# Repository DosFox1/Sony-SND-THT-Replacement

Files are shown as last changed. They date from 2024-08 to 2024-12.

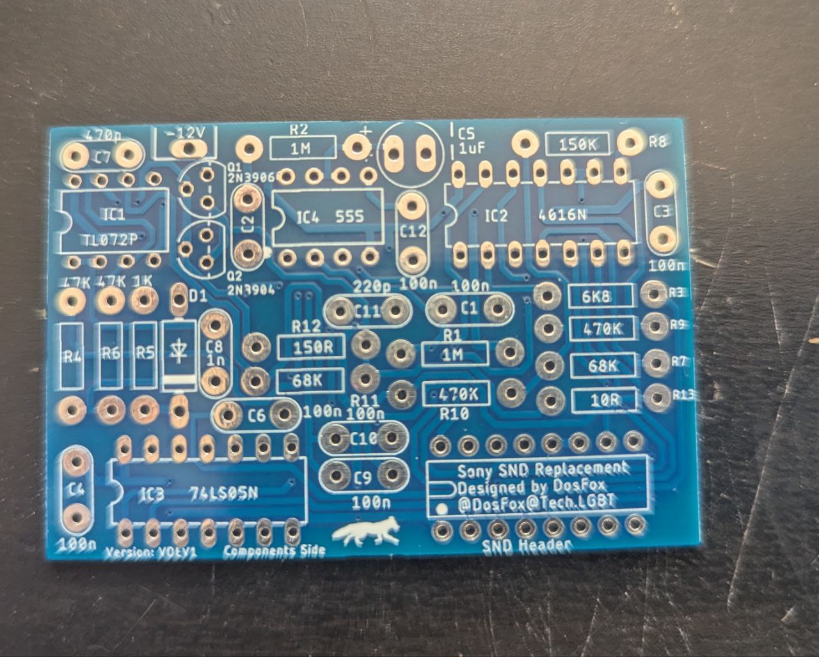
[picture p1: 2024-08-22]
Images/Sony SND Replacement Bare PCB.png

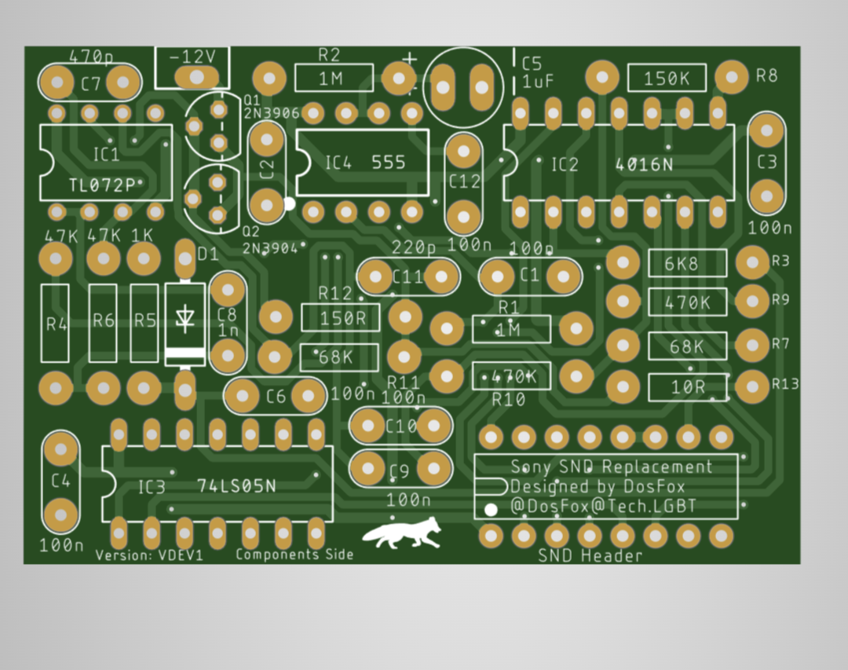
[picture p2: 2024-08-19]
Images/Sony SND Replacement Front.png

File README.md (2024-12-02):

# Sony SND THT Replacement 
A replacement for the Sony SND IC (part number 343-0045-A) as used on the Macintosh Plus, SE and others.
This was designed for the Macintosh Plus Clone project, but should be able to be used in other Macintoshes.

Screenshot_20240816-162321~2

**So, What Is It?**

The Sony SND is a custom IC, developed by Sony for the Macintosh Plus. 
It has three main functions - volume control, audio amplification, as well as providing the POR (Power On Reset) signal for the system. 
The original IC represents one of three custom pieces of silicon found with the Macintosh Plus. 

This board replaces the original Sony SND with equivalent circuitry. 
The Power On Reset deisgn is taken from the book _The 68000 microprocessor : hardware and software principles and applications_
This is currently available on the internet archive: https://archive.org/details/68000microproces00jame

Whereas the design for the audio amplification and volume control was taken from the original Macintosh 128/512 schematics:
https://forums.macrumors.com/threads/macintosh-512k-schematic.2291827/

**Parts List**

The SND is comprised of relatively easy to find, off the shelf parts:
```blocks
C1       100n 50V       100N_TH_CAP            CAP_5.08MM_PITCH 1
C2       100n 50V       100N_TH_CAP            CAP_5.08MM_PITCH 1
C3       100n 50V       100N_TH_CAP            CAP_5.08MM_PITCH 1
C4       100n 50V       100N_TH_CAP            CAP_5.08MM_PITCH 1
C5       1u 50V         1U_TH_ELEC_CAPVERTICAL CAP_ELECTROLYTIC 1
C6       100n 50V       100N_TH_CAP            CAP_5.08MM_PITCH 1
C7       470p 50V       470P_TH_CAP            CAP_5.08MM_PITCH 1
C8       1n 50V         1N_TH_CAP              CAP_5.08MM_PITCH 1
C9       100n 50V       100N_TH_CAP            CAP_5.08MM_PITCH 1
C10      100n 50V       100N_TH_CAP            CAP_5.08MM_PITCH 1
C11      220p 50V       220P_TH_CAP            CAP_5.08MM_PITCH 1
D1       5.1V Zener     ZENER-DIODEF126-10     F126Z10          1
IC1      TL072P         TL072P                 DIL08            1
IC2      4016N          4016N                  DIL14            1
IC3      74LS05N        74LS05N                DIL14            1
IC4      555            555P                   DIP08            1
CN1      Header         Turned Pin Header      DIP16 Header     16
Q1       2N3906         2N3906                 TO92             1
Q2       2N3904         2N3904                 TO92D            1
R1       1M             1M_TH_RESISTOR         RESISTORTHRUHOLE 1
R2       1M             1M_TH_RESISTOR         RESISTORTHRUHOLE 1
R3       6k8            6K8_TH_RESISTOR        RESISTORTHRUHOLE 1
R4       47k            47K_TH_RESISTOR        RESISTORTHRUHOLE 1
R5       1k             1K_TH_RESISTOR         RESISTORTHRUHOLE 1
R6       47k            47K_TH_RESISTOR        RESISTORTHRUHOLE 1
R7       68k            68K_TH_RESISTOR        RESISTORTHRUHOLE 1
R8       150k           150K_TH_RESISTOR       RESISTORTHRUHOLE 1
R9       470k           470K_TH_RESISTOR       RESISTORTHRUHOLE 1
R10      470k           470K_TH_RESISTOR       RESISTORTHRUHOLE 1
R11      200k           200K_TH_RESISTOR       RESISTORTHRUHOLE 1
R12      150R           150R_TH_RESISTOR       RESISTORTHRUHOLE 1
R13      10R            10R_TH_RESISTOR        RESISTORTHRUHOLE 1
```

All components are through hole, and are designed to be easily soldered. 
The PCB can be sourced from your favoured fab house, I prefer JLCPCB (sorry PCBWay) - and only cost $4 for five boards. 

**Assembly Notes and Errata**

This design is the initial VDEV1 version of the SND replacement, and has been tested with the Macintosh Plus Clone project.



The design (being through hole) is unlikely to fit into an existing Macintosh chassis, and was designed as a
"first stab" attempt at making a replacement SND. It is anticipated that a secondary improved SMD design will be more suited to this application.

The zener diode at D1 theoretically should be a 1N5231, but any similar 5.1v zener will suffice. 

Assembly should be fairly straight forward for those with some experience with electronic assembly.

Additionally, as the audio section is based off the original Macintosh 128K, -12V is required, which is not provided by the SND header. 
-12V can be tapped directly from the logic board - either from pin 2 (central pin) of the 7905 -5v regulator, pin 8 of the audio/power header
or from pin 5 of the MC3488 line driver. 
I heavily suggest checking with a multimeter before installation - this may damage the SND adapter, the Macintosh board, or both.

The board should be fitted so that the majority of the boards cover the 6522 and Z8530. It may be necessary to add a standard IC socket to raise the board.

Note - VDEV1 boards were assembled and worked first time. Also note that a TL082 can be subsistuted instead of the TL072 if needed.

# Important Assembly Note!
R11 should be a 200K resistor. It is erroneously marked as a 68K on VDEV1 boards. 
This has been fixed in V1.0

# Very Important Note:
Additionally - resistor R21 on the Macintosh Board itself needs to be snipped off, as this is a 47 ohm pull up to 5V on the POR circuit. 
No clue why Sony designed it this way, but it needs to be removed (or replaced with a 1M, and R1 on the Sony SND replacement DNF'd).

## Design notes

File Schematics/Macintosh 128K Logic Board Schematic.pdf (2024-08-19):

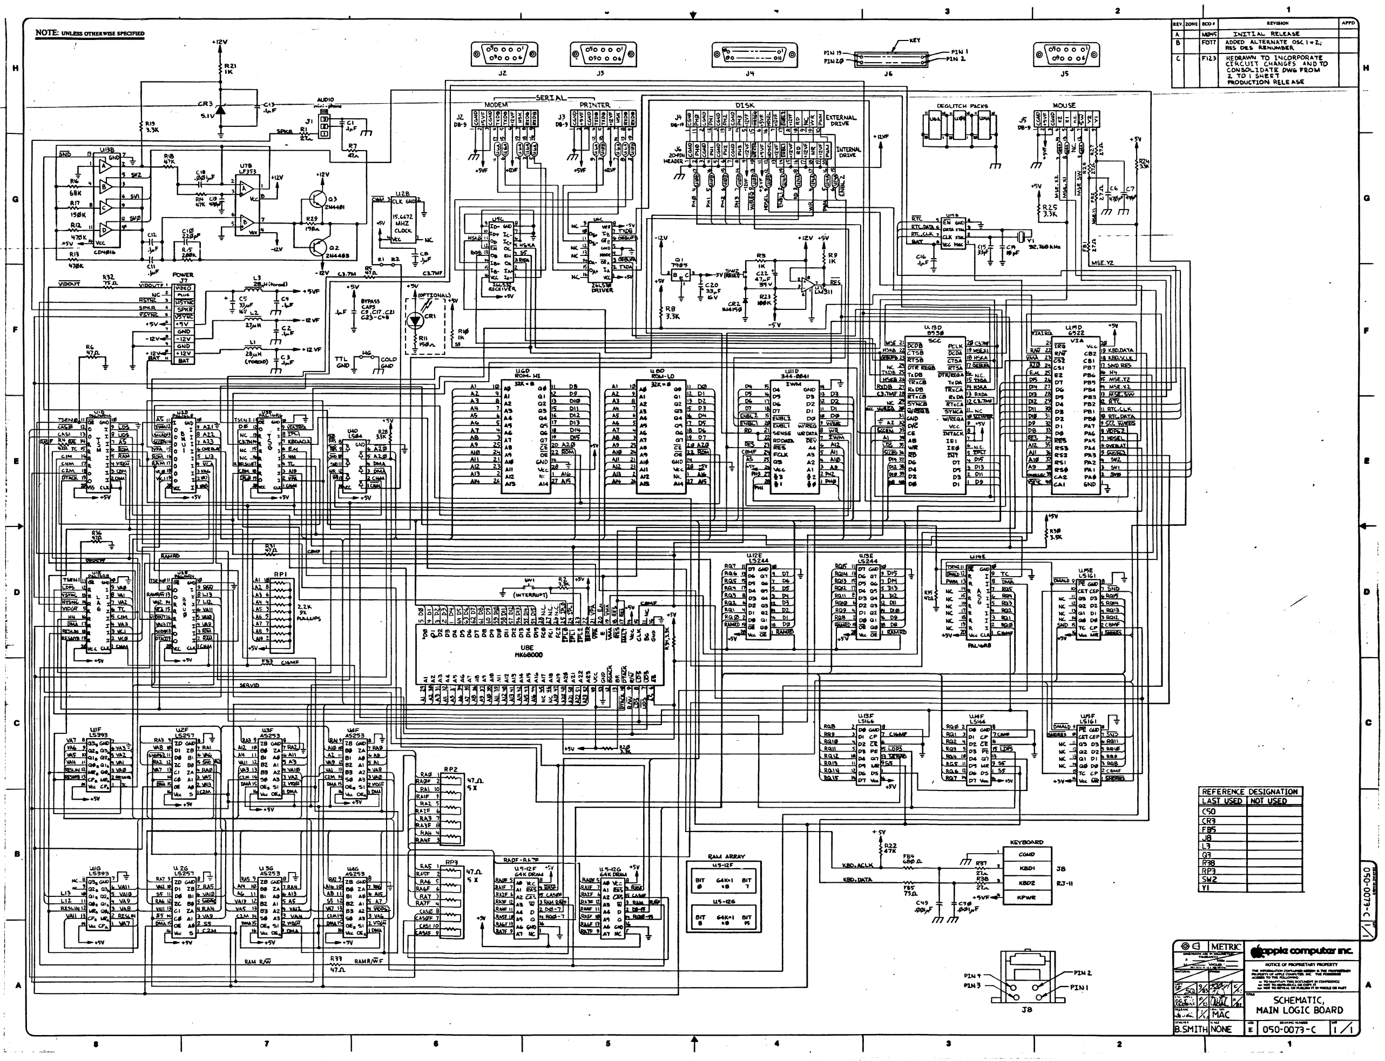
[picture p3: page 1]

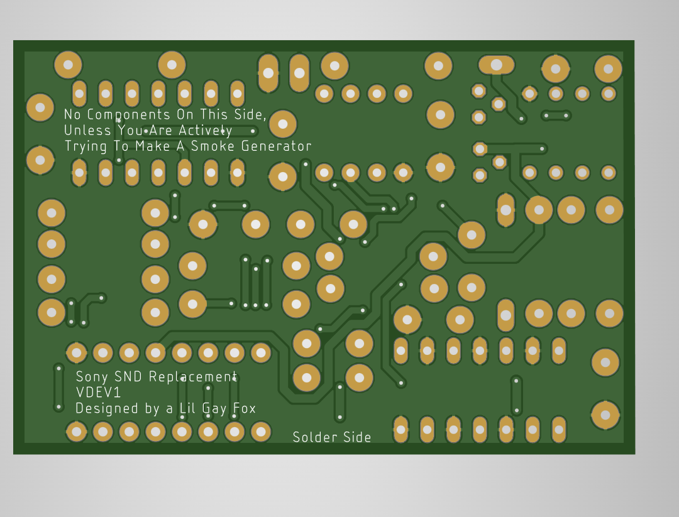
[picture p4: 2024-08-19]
Images/Sony SND Replacement Back.png

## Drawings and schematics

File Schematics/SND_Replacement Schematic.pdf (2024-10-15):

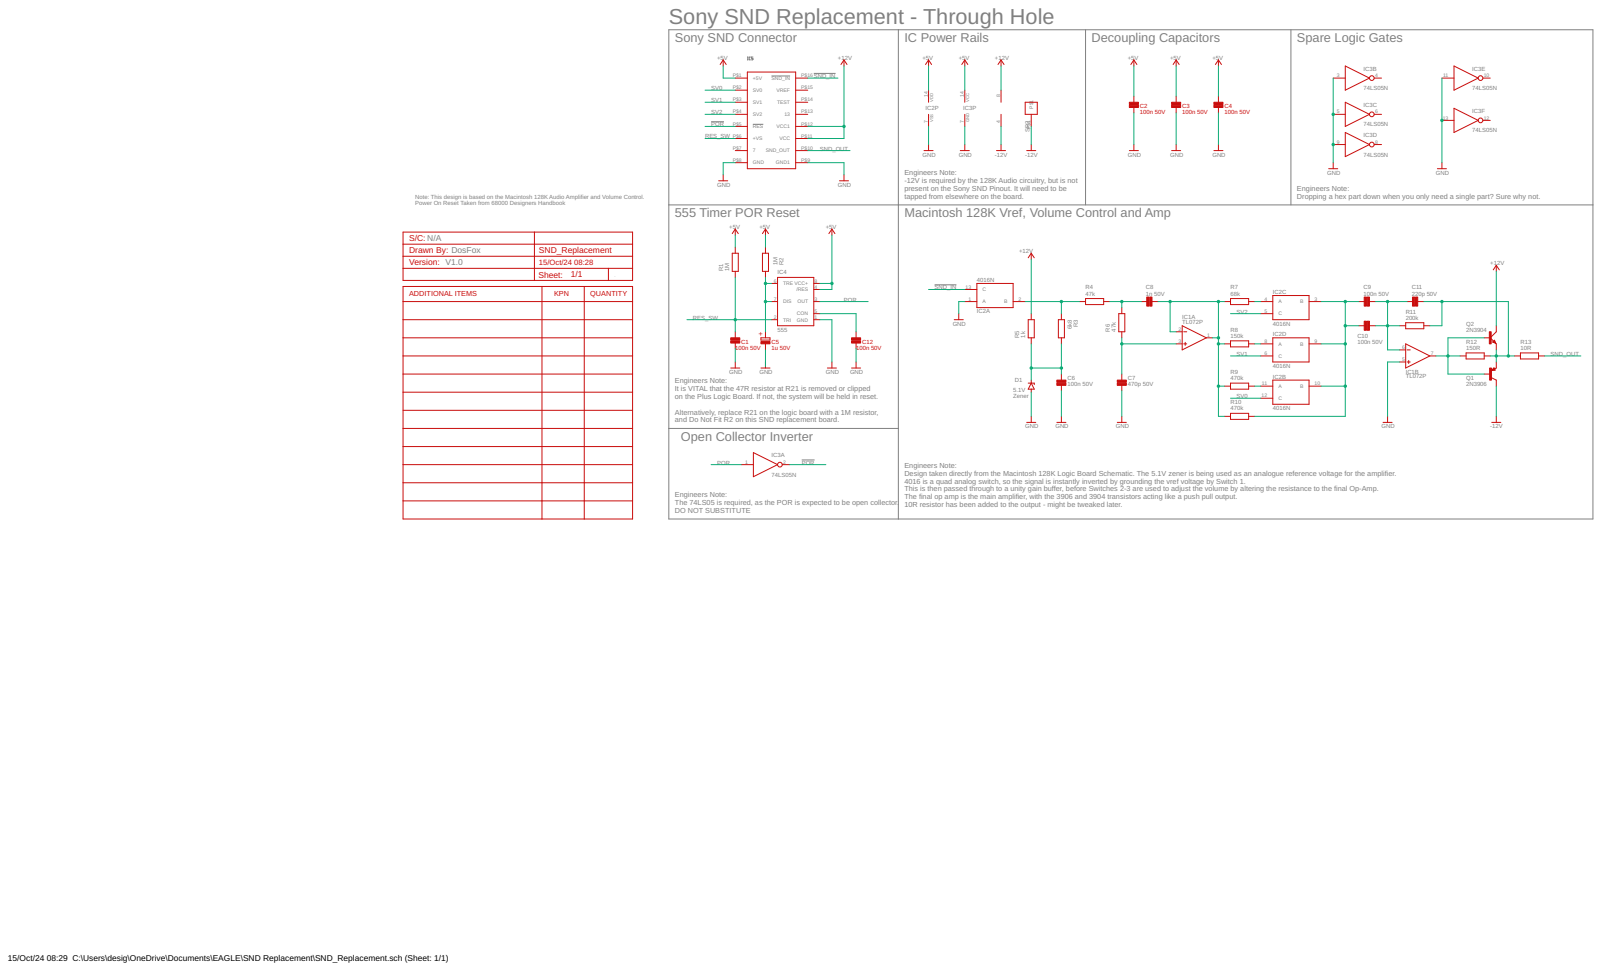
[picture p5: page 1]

Sony SND Replacement - Through Hole

Engineers Note: -12V is required by the 128K Audio circuitry, but is not

present on the Sony SND Pinout. It will need to be

Note: This design is based on the Macintosh 128K Audio Amplifier and Volume Control. Power On Reset Taken from 68000 Designers Handbook

Dropping a hex part down when you only need a single part? Sure why not. V1.0

Macintosh 128K Vref, Volume Control and Amp

S/C: N/A
Drawn By: DosFox | SND_Replacement
Version: | 15/Oct/24 08:28

Sheet: 1/1 | A1

Engineers Note:
It is VITAL that the 47R resistor at R21 is removed or clipped
on the Plus Logic Board. If not, the system will be held in reset. Alternatively, replace R21 on the logic board with a 1M resistor, and Do Not Fit R2 on this SND replacement board.

Design taken directly from the Macintosh 128K Logic Board Schematic. The 5.1V zener is being used as an analogue reference voltage for the amplifier. 4016 is a quad analog switch, so the signal is instantly inverted by grounding the vref voltage by Switch 1. This is then passed through to a unity gain buffer, before Switches 2-3 are used to adjust the volume by altering the resistance to the final Op-Amp. The final op amp is the main amplifier, with the 3906 and 3904 transistors acting like a push pull output. 10R resistor has been added to the output - might be tweaked later.

The 74LS05 is required, as the POR is expected to be open collector. DO NOT SUBSTITUTE

15/Oct/24 08:29 C:\Users\desig\OneDrive\Documents\EAGLE\SND Replacement\SND_Replacement.sch (Sheet: 1/1)

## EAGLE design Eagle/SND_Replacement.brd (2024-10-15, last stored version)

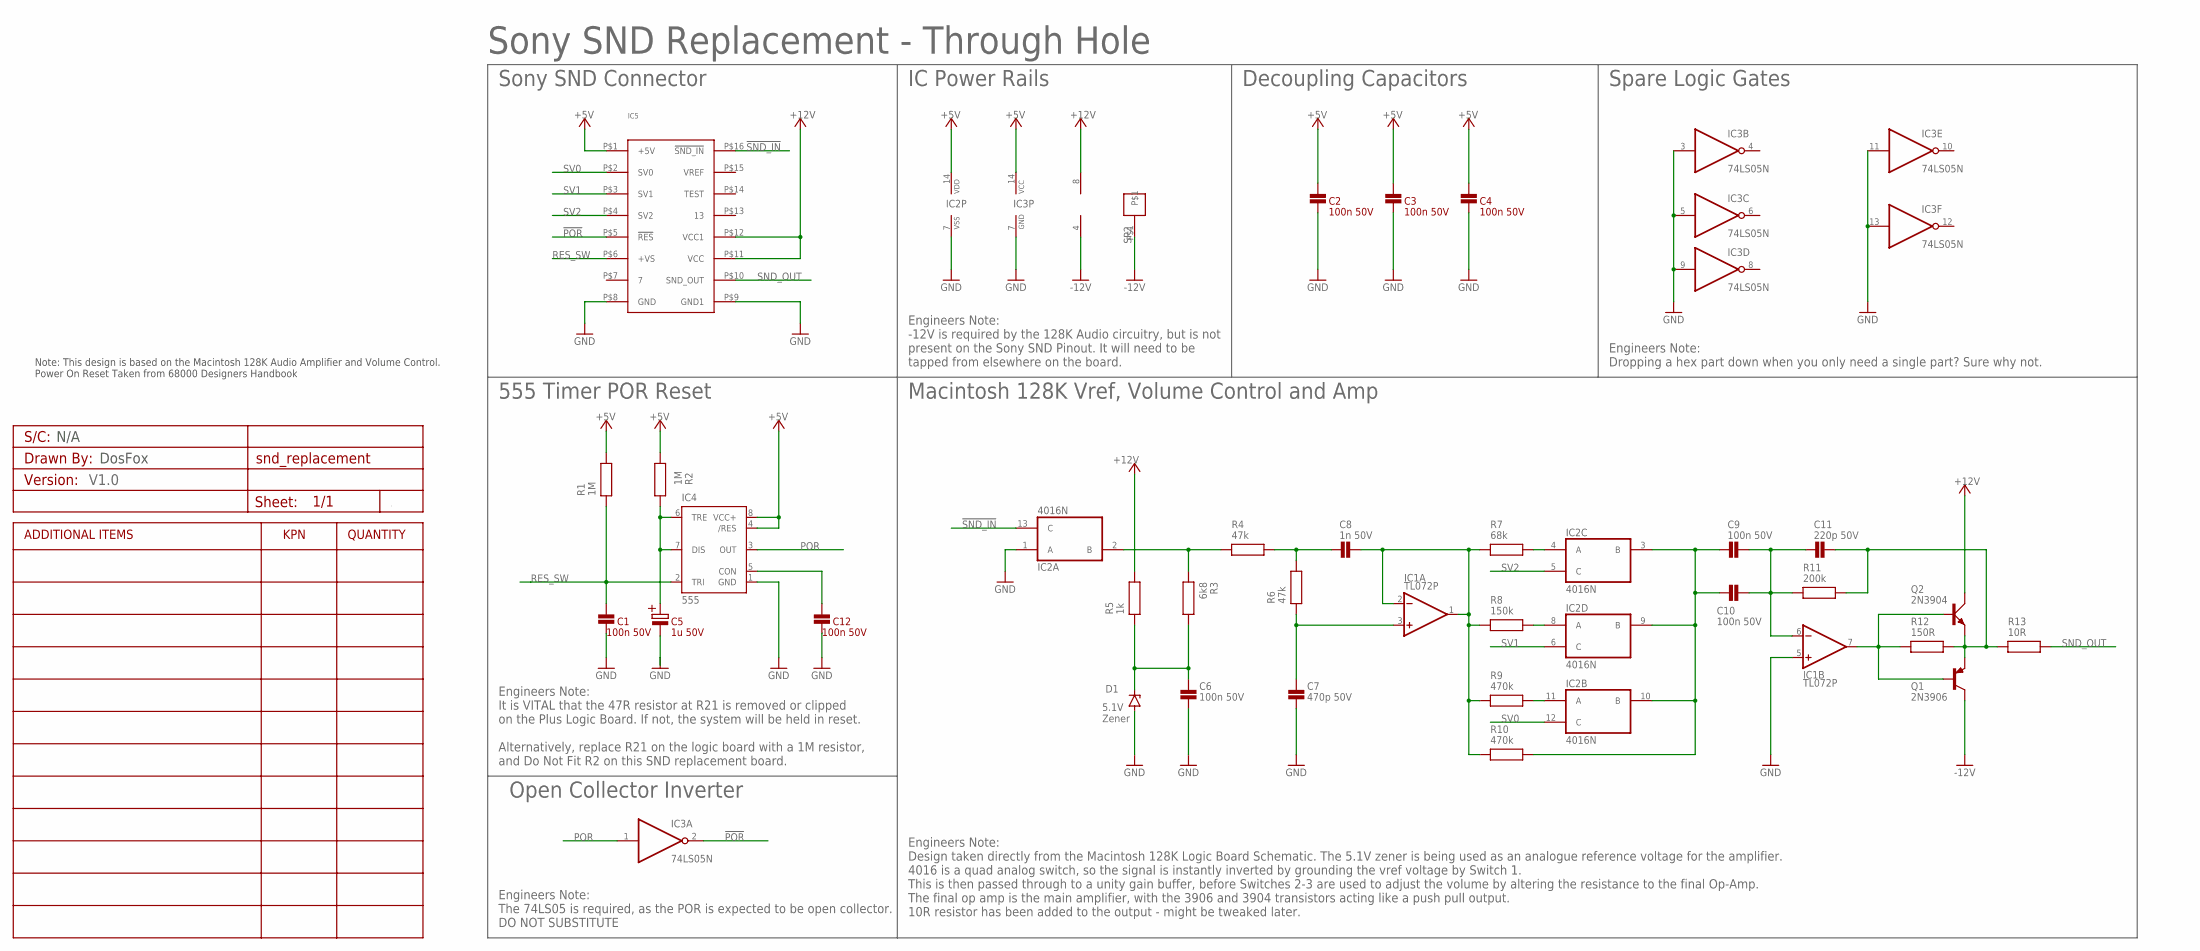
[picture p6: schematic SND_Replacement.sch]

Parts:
A1: V1.0; PCB_CUSTOM_DETAILS
C1, C2, C3, C4, C6, C9, C10, C12: 100n 50V; CAP_5.08MM_PITCH
C5: 1u 50V; CAP_ELECTROLYTIC
C7: 470p 50V; CAP_5.08MM_PITCH
C8: 1n 50V; CAP_5.08MM_PITCH
C11: 220p 50V; CAP_5.08MM_PITCH
D1: ZENER-DIODEF126-10; F126Z10
IC1: TL072P; DIL08
IC2: 4016N; DIL14
IC3: 74LS05N; DIL14
IC4: 555; DIP08
IC5: SND; DIP16
Q1: 2N3906; TO92
Q2: 2N3904; TO92D
R1, R2: 1M; RESISTORTHRUHOLE
R3: 6k8; RESISTORTHRUHOLE
R4, R6: 47k; RESISTORTHRUHOLE
R5: 1k; RESISTORTHRUHOLE
R7: 68k; RESISTORTHRUHOLE
R8: 150k; RESISTORTHRUHOLE
R9, R10: 470k; RESISTORTHRUHOLE
R11: 200k; RESISTORTHRUHOLE
R12: 150R; RESISTORTHRUHOLE
R13: 10R; RESISTORTHRUHOLE
SP2: 1PIN

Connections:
!POR: IC3.2 (O), IC5.P$5 (!RES)
!SND_IN: IC2.13 (C), IC5.P$16 (!SND_IN)
+5V: C2.P$2, C3.P$2, C4.P$2, IC2.14 (VDD), IC3.14 (VCC), IC4.4 (/RES), IC4.8 (VCC+), IC5.P$1 (+5V), R1.P$2, R2.P$2
+12V: IC1.8 (V+), IC5.P$11 (VCC), IC5.P$12 (VCC1), Q2.C, R5.P$2
-12V: IC1.4 (V-), Q1.1 (C), SP2.P$1
GND: C1.P$1, C2.P$1, C3.P$1, C4.P$1, C5.P$2, C6.P$1, C7.P$1, C12.P$1, D1.A, IC1.5 (+IN), IC2.1 (A), IC2.7 (VSS), IC3.3 (I), IC3.5 (I), IC3.7 (GND), IC3.9 (I), IC3.11 (I), IC3.13 (I), IC4.1 (GND), IC5.P$8 (GND), IC5.P$9 (GND1)
unnamed: IC2.2 (B), R3.P$1, R4.P$1
unnamed: C12.P$2, IC4.5 (CON)
unnamed: C9.P$1, C10.P$1, IC2.3 (B), IC2.9 (B), IC2.10 (B), R10.P$2
unnamed: C8.P$1, R4.P$2, R6.P$2
unnamed: C6.P$2, D1.C, R3.P$2, R5.P$1
unnamed: C7.P$2, IC1.3 (+IN), R6.P$1
unnamed: IC2.4 (A), R7.P$2
unnamed: IC2.8 (A), R8.P$2
unnamed: IC2.11 (A), R9.P$2
unnamed: C9.P$2, C10.P$2, C11.P$1, IC1.6 (-IN), R11.P$1
unnamed: C8.P$2, IC1.1 (OUT), IC1.2 (-IN), R7.P$1, R8.P$1, R9.P$1, R10.P$1
unnamed: C11.P$2, Q1.3 (E), Q2.E, R11.P$2, R12.P$2, R13.P$1
unnamed: IC1.7 (OUT), Q1.2 (B), Q2.B, R12.P$1
POR: IC3.1 (I), IC4.3 (OUT)
RES_SW: C1.P$2, IC4.2 (TRI), IC5.P$6 (+VS), R1.P$1
RES_SW1: C5.P$1, IC4.6 (TRE), IC4.7 (DIS), R2.P$1
SND_OUT: IC5.P$10 (SND_OUT), R13.P$2
SV0: IC2.12 (C), IC5.P$2 (SV0)
SV1: IC2.6 (C), IC5.P$3 (SV1)
SV2: IC2.5 (C), IC5.P$4 (SV2)

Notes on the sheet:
Note: This design is based on the Macintosh 128K Audio Amplifier and Volume Control. Power On Reset Taken from 68000 Designers Handbook
DosFox
N/A
5.1V Zener
Sony SND Replacement - Through Hole
Sony SND Connector
IC Power Rails
Decoupling Capacitors
Spare Logic Gates
555 Timer POR Reset
Open Collector Inverter
Macintosh 128K Vref, Volume Control and Amp
Engineers Note: Design taken directly from the Macintosh 128K Logic Board Schematic. The 5.1V zener is being used as an analogue reference voltage for the amplifier. 4016 is a quad analog switch, so the signal is instantly inverted by grounding the vref voltage by Switch 1. This is then passed thro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
Engineers Note: It is VITAL that the 47R resistor at R21 is removed or clipped on the Plus Logic Board. If not, the system will be held in reset. Alternatively, replace R21 on the logic board with a 1M resistor, and Do Not Fit R2 on this SND replacement board.
Engineers Note: The 74LS05 is required, as the POR is expected to be open collector. DO NOT SUBSTITUTE
Engineers Note: -12V is required by the 128K Audio circuitry, but is not present on the Sony SND Pinout. It will need to be tapped from elsewhere on the board.
Engineers Note: Dropping a hex part down when you only need a single part? Sure why not.

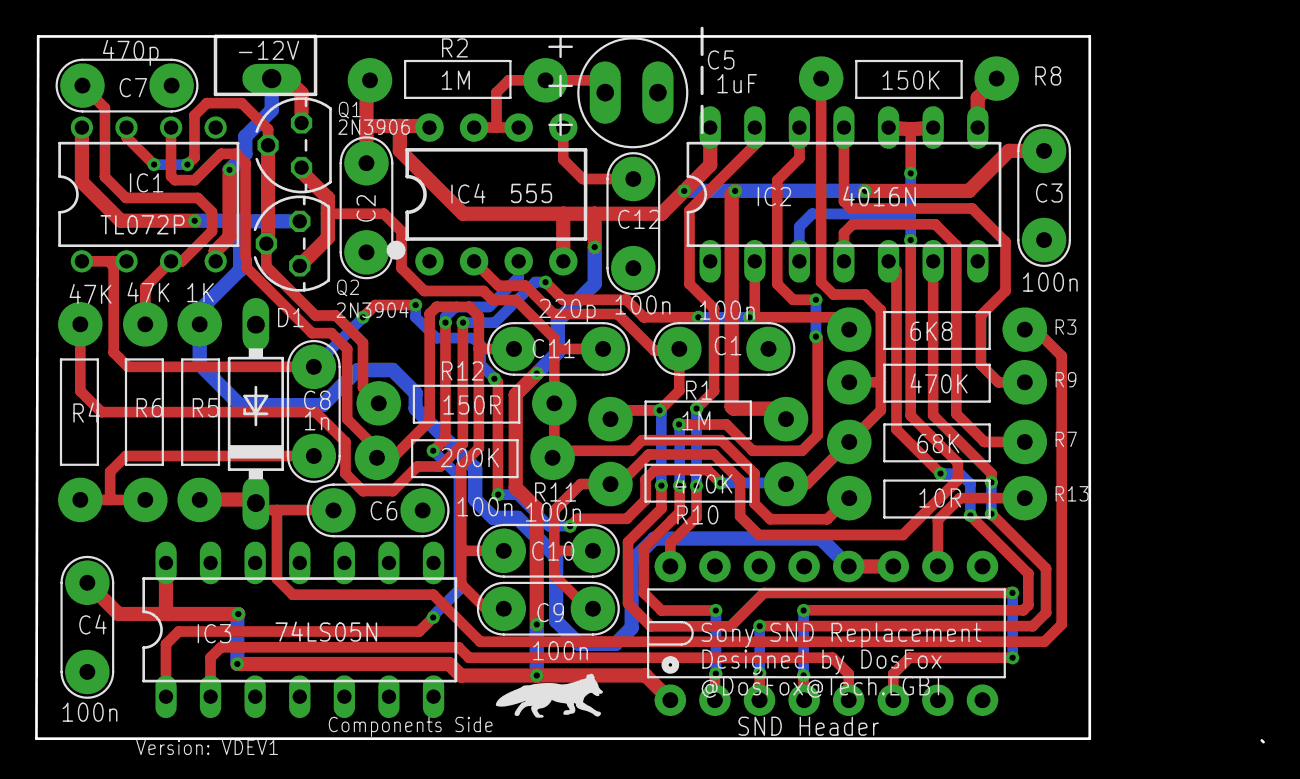
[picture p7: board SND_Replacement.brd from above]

Board: 2 copper layers, 60.0 x 40.0 mm, 35 parts (0 on the bottom side), 26 nets.

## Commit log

2024-10-04 Update SND_Replacement BOM.txt
2024-10-15 Add files via upload
    Resolved issue regarding R11 (200K rather than original 68K
    [SND_Replacement.brd, SND_Replacement.sch]
2024-10-15 Rename SND_Replacement.pdf to SND_Replacement Schematic.pdf
2024-10-15 Rename SND_Replacement_V1.0.zip to SND_Replacement_V1.0 Gerbers.zip
2024-10-15 Rename Macintosh 128K Logic Board Schematic.pdf to Schematics/Macintosh 128K Logic Board Schematic.pdf
2024-10-15 Rename Macintosh Plus Logic Board Schematic.pdf to Schematics/Macintosh Plus Logic Board Schematic.pdf
2024-10-15 Rename SND_Replacement Schematic.pdf to Schematics/SND_Replacement Schematic.pdf
2024-10-15 Rename SND_Replacement BOM.txt to BOM/SND_Replacement BOM.txt
2024-10-15 Rename SND_Replacement_V1.0 Gerbers.zip to Gerbers/SND_Replacement_V1.0 Gerbers.zip
2024-10-15 Rename Sony SND Replacement Bare PCB.png to Images/Sony SND Replacement Bare PCB.png

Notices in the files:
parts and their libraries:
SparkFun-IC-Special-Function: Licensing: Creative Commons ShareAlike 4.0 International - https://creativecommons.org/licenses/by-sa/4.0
